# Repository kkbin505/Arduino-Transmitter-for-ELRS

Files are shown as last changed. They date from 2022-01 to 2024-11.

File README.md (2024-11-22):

# Simple TX

现已增加中文介绍，详情请看Wiki页面

This is an Arduino based RC transmitter TX. I want to design a RC transmitter (soft and hardware) that is simple to build, and use arduino board wich I am familler with, and it should supoort ELRS.

微信图片_20220213205906

video:

https://www.youtube.com/watch?v=BPLFkZUoV28

# Features:
- Support ExpressLRS 2.4G external TX module
- Up to 500Hz packet rate
- 4 analog channel
- 4 AUX channel

This project includes code, stl file for transmitter shell and pcb board, you can easily diy your own rc transmitter from arduino development board in a very simple way.

I have tested for 6 month since the first prototype (mod from an old Devo7), it works pretty well.

 * Simple TX is distributed in the hope that it will be useful, but WITHOUT ANY WARRANTY. 

I use superslim module in the shell, but any esp32 based tx module should be working.

It was tested for ELRS 1.0 and 2.0.

### Update:

### 2024/11/7 add 3 stage AUX channel
In branch 2.X maintance:
Because I have started flying fixed wing with iNav, current 7 channels are not enougth. So I added channel 8 and changed channel 6 (AUX2) from 2 postion switch to 3 postion. This is also for Betaflight. The 3 postion have to use 2 digital pins, currently I am using D3 and D8.

The current digital pin:

D2 - AUX3 

D3 - AUX2 low

D8 - AUX2 high

D4 - AUX1

D5 - AUX4

D6 - BUZZER

D7 - LED

### The development was moved to VS code 

### 2022/11/5 Move IDE to VSCODE and Arduino Extension

Add buzzer support on pin 6

The PIO becomes unusable dude to unstalbe network, so I switch back to arduino extension, still in VSCODE, because the original Arduino IDE is low efficient.

The code still works in Arduino IDE, you can compile in both enviroment

The PIO will be saved in a seprate branch and will unliked be updated

### 2022/6/3 Optimize Calibration

1. Add center stick calibration
2. Optimze channel reverse
	use 4 values to handdle reverse in config.h
	
// Define Reverse 1 = reverse, 0 = normal
	
Is_Aileron_Reverse  =1;
	
Is_Elevator_Reverse =1;
	
Is_Throttle_Reverse =0;
	
Is_Rudder_Reverse   =0;

### 2022/5/29 Calibration added

Calibration function added by erstec in Platformio_test_branch, thanks

1. enter debug mode by uncomment #define DEBUG
2. flash firmware to arduino nano
4. open serial monitor at 115200 baud, center stick and keep for 5 seconds
5. move stick full range within 20 seconds untill you see "Calibration Done"
6. comment //#define DEBUG and flash firmware to arduino nano
7. test in bf configurator
8. done

### 2022/4/6 Test branch

platformio

### Update Log 2022/4/3

Add Test branch for ppm output

### Update Log 2022/3/26

Update STL File：

Solve gimbal & switch interference

Add battery tray

ASSEMBLE

### Update Log 2022/3/20

Update PPM to ELRS library, siginal is more stable, still need more test

https://github.com/kkbin505/Arduino-Transmitter-for-ELRS/tree/main/PPMtoCRSF

### Update Log V0.9.3
Increase baud rate to 400K

*** In 400k baud, theoretical maxmum packet rate is 500Hz (400000/320bit per second, 1.6ms per frame). RC data pcket is 32byte=320bit(plus 1 start bit and 1 end bit).

Now simpleTX is supporting 500Hz

Add 3rd pre seeting for 500Hz 25mW

Gestrue:
Hold AILERON left and ELEVATOR up at power up.

### Update Log V0.9.2
Update cmd to elrs 2.0 (power setting commond of 2.0 is different from 1.0)

Re write gimbal calibation method, add center stick offset in config file

### Update Log V0.9.1
Add 2 pre settings for power and package rate:

Now you can enter setting 1 and 2 by gesutre:

Setting 1:
//250Hz 25mW

Hold AILERON left and ELEVATOR down at power up.

Setting 2:
//150Hz 100mW

Hold AILERON right and ELEVATOR up at power up.

Center stick will keep your previous setting.

Due to the hardware limitation of the ATMega328p, the follow functions are not supported:

* The 328p do not support inverted UART (which OpenTX use), there are 2 options:
	1. Tun  UART_INVERTED off.
	2. Adding a digital invert IC (I tested with SN74LS06N)

** Telemetray is off, 328p do not support half duplex.

The uart logic voltage of ESP32 is 3.3V, my ATMega328p is 5V. However mine TX work fine, it seems ESP32 UART is 5V tolerance.

#### Tips
Default RC channel order is AETR, you can change channel order whatever you like, by changing the RC channel order.
Current gimbal calibratin method is complex (but you need to do only once):
- Enter debug mode by delete "//" before #define DEBUG
- Flash with arduino IDE
- Open serialmonitor change baud rate to 115200
- Record max and min RC channel value and write in map() function (reverse order if neede)
   example:map(Aileron_value,893,223,RC_CHANNEL_MIN,RC_CHANNEL_MAX)
- Add "//" back before #define DEBUG
- Flash with arduino IDE

There are many amazing Expreslrs handset. But I want a simple arduino based transmitter for my DIY 2.4G external TX module.

https://youtu.be/PrfSfnqcBgk

### Add PCB V0.9

I replace the control board with my PCB and system.

微信图片_20220123195005

### 1. Project Intro:

### 1.1 Hardware (PCB)

In PCB folder, you can find the PCB and BOM, the PCB is designed in Easyeda and files in Gerber type. I orderd my PCB use the Gerber file from JLCpcb.

EasyEDA(标准版) - 免费、易用、强大的在线电路设计软件 - Google Chrome 2022_1_23 19_47_16

The PCB is v0.9 means it is not complete, but it works well at least for me. 

The version includes 4 digital switch, but I forget to wire out the LED pint, so I use one channel for LED only 3 digital available. 

The analogy channel support 3.3v gimbal (hall and poentional meter both works), the pin use 1.25 6p plug, it is the same pin order as most frsky gimbal (M7 for example). If you use orther gimbal pay attention to the pin order. I find jumper gimbal reversed GND(red) and 3.3V(black).

I powered my board with 2S battery, the arduino nano have a decent LDO （ASM1117）, and the ELRS module also powerd from 2S.

### 1.2 Firmware

All source codes are in SimpleTX folder.

It is writen in arduino frame use VScode, but arduino IDE should also work.

### 1.3 CAD-Model

3 versions of transmitter shell are available.

1 is a remix from https://github.com/cruwaller/elrs_handset



I removed 2 switch, and modify switch in front side from Switches to Tango2 like switch



Front_Shell_REV-A_M7_kkbin_modify.stl

2 is my design, it is compatibal with jumper TX 12 hall gimbal, very compact.



SimpleTX_Top_v15.stl

3 is for X9 lite gimbal, it feels too big for me.

!!! Do not solder the buzzer, need to add triode in next version, I burned my board.
buzzer

This Transmitter is inspired by cruwallero:
https://github.com/cruwaller/elrs_handset

Some code are based on  Pawel's amazing work on SBUS generate code.

https://quadmeup.com/generate-s-bus-with-arduino-in-a-simple-way/

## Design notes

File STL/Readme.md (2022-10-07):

Add STL file for print

微信图片_20220213205906

ASSEMBLE

Add a modify file from: https://github.com/cruwaller/elrs_handset/tree/master/revision_A/shell

Delete 2 top side switchs, modify front side switch to rectangle 19*7mm switch， give this design more tango2 kind of taste

Add gimbal protect for M7, print in TPU 20%

Add a open on the lower side for usb

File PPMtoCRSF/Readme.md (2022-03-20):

PPM to ELRS conveter

Use simpleTX PCB to make a ppm to ELRS converter

Plug PPM to D2 (switch 4 in pcb) and GND

This code is highly expermental, and unstable.

Make sure your transmitter output ppm correctly, otherwise the TX will receive noise singal, and transmit unexpected singal.

Use this arduino library:

https://github.com/DzikuVx/PPMReader

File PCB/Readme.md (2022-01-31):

Add PCB V0.9

BOM :
1. Frsky M7 Gimbal *2
2. Arduino Nano
3. XH2.45 3P *6
4. PH2.0 2P
5. 1.25 6P
6. 2 Position Switch *5
7. LED *1
8. 100 ohm resister 
9. 10K 0805 resister
10. 20K 0805 resister
11. UFL to SMA connector
12. 2.4G SMA antenna
13. ExpressLRS 2.4G TX module
14. 2S battery
15. PCB https://oshwlab.com/kkbinmail/arduino_transmitter

Build order:

1. Print shell from:https://github.com/cruwaller/elrs_handset/tree/master/revision_A/shell
2. Order PCB from JLB PCB
3. Sold 10K and 20K resiter to PCB
4. Sold 1.25 6P male header
5. Sold Arduino Nano
6. Sold XH2.45 (Double check the pole of the battery header, make sure ground is to ground)
7. Sold PH2.0
8. Down load firmware
9. Build and Flash to Arduino Nano with IDE
10. Flash TX module use ExpressLRS un-check UART_INVERTOR & OpenTX_SYNC
11. Assemble switch to shell
12. Assemble M7 Gimbal
13. Assemble SMA connector
14. Connect everything

SCHEAM

EasyEDA(标准版) - 免费、易用、强大的在线电路设计软件 - Google Chrome 2022_1_23 19_47_16

微信图片_20220123194957

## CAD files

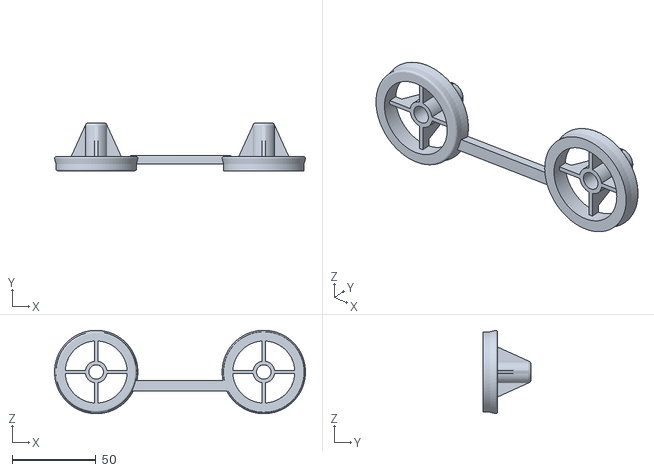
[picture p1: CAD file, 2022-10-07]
STL/Front_Shell_REV-A_M7_kkbin_modify_gimbal Cover v2.stl
149.8 x 28.4 x 49.8

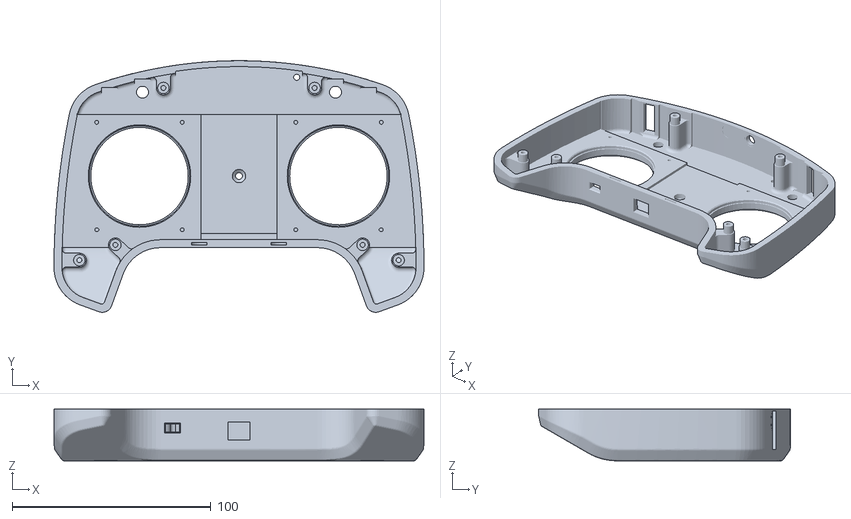
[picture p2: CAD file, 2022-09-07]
STL/Front_Shell_REV-A_M7_kkbin_modify.stl
186.0 x 126.5 x 26.0

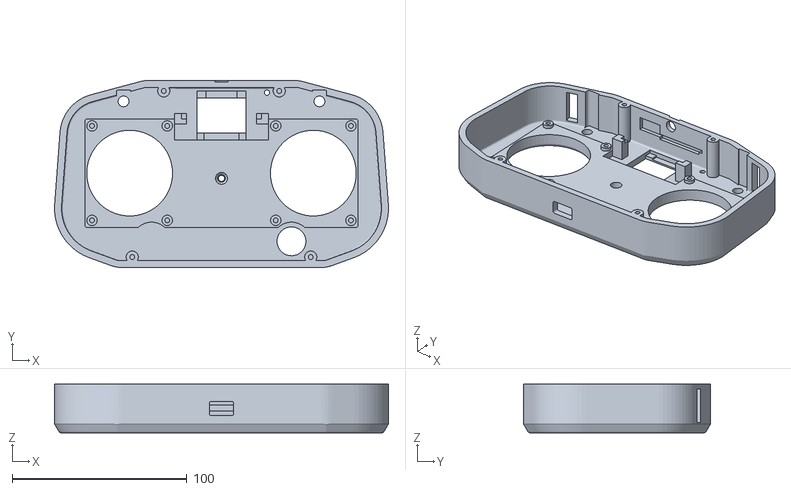
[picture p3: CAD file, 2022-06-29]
STL/SimpleTX_Top_Frsky_X9Lite_S.stl
190.9 x 107.0 x 28.0

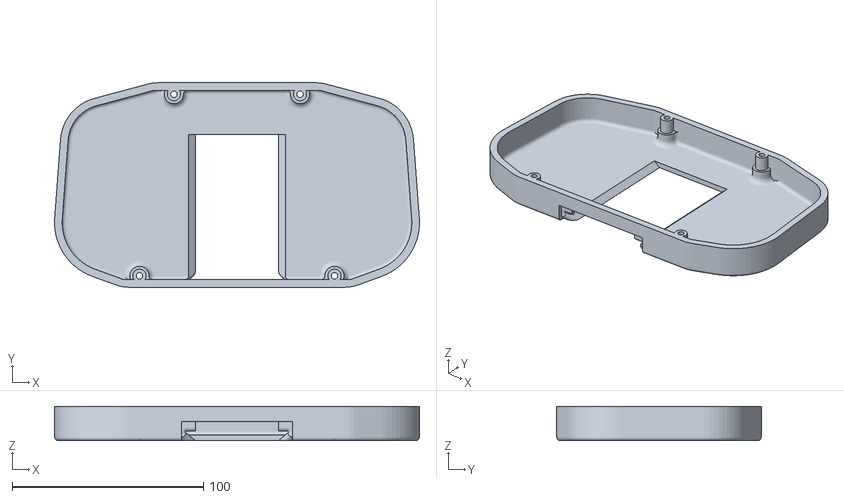
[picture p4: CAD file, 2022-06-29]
STL/SimpleTX_Buttom Frsky_X9Lite_S.stl
190.9 x 107.0 x 18.0

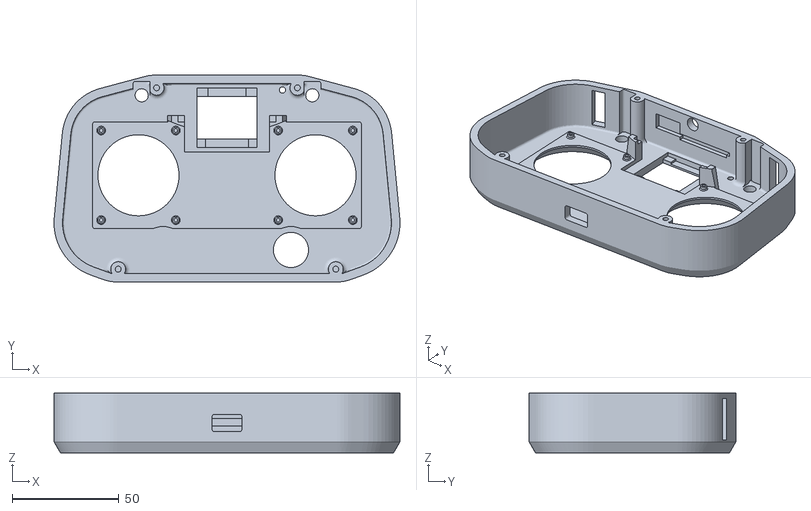
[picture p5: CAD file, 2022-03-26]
STL/SimpleTX_Top_v15.stl
162.2 x 97.0 x 28.0

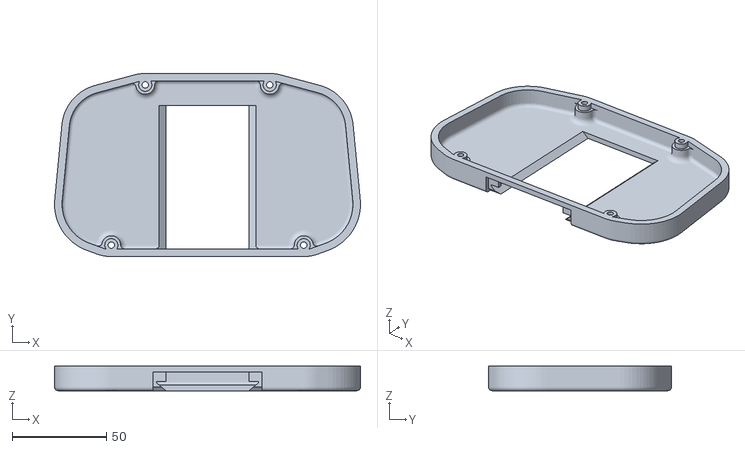
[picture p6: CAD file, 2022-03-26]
STL/SimpleTX_Buttom v15.stl
162.2 x 97.0 x 13.0

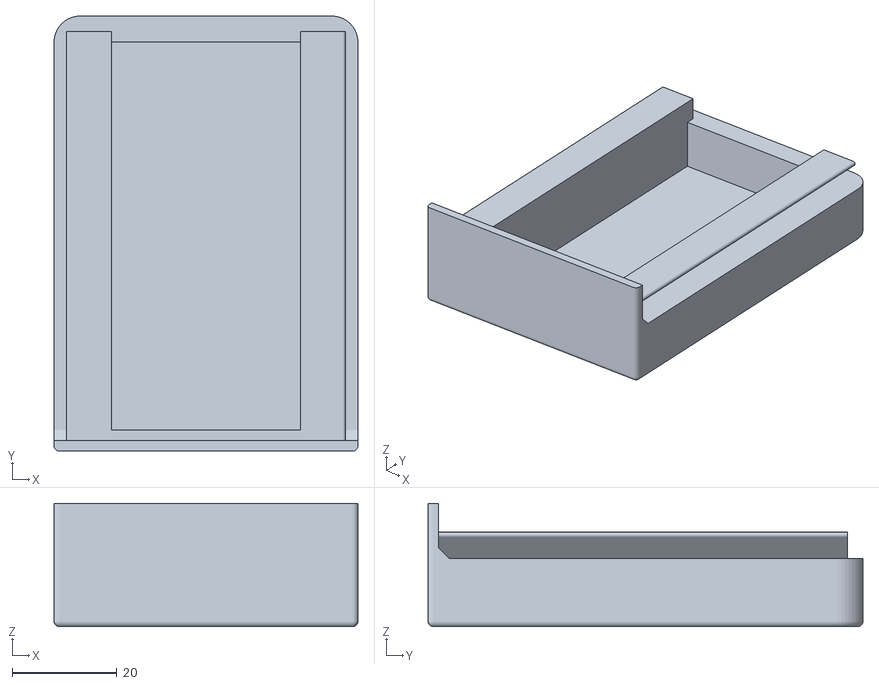
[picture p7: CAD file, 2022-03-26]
STL/SimpleTX_Battery_Bay v15.stl
58.0 x 83.0 x 23.5

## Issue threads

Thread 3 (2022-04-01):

Why not just use ELRS+stick for Transmitter

hjchjcjh, 2022-04-01:
It is recommended to integrate all applications into the ELRS, because esp32 has many ADCs and the joystick can be directly connected to the ADC of ESP32,

kkbin505, 2022-04-05:
That a good suggestion.
The transmitter as it's name is to keep code simple. If integrate all staff in the esp32, the code will be too complex.
Second, simpletx decouple the fast development of the expresslrs repo, the main code of simpletx will be compatabile from expresslrs 1.0 all the way to 2.3 and further. It is easier to maintain.
If you are looking for directly ADC to expresslrs, you can alway find information in the expresslrs handset repo:
https://github.com/ExpressLRS/ExpressLRS-Hardware

Closed 2022-04-05.

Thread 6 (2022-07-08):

About RC Channel

mrAyaz, 2022-07-08:
thanks for this wonderful project. Can you tell me how many channels this project supports. I need 10 channels is this possible?

kkbin505, 2022-07-12:
Thanks for your support.
The Arduino nano I used have (A0 to A7) 8 analogy IO and (D2 to D13) 12 digital IO, so it can have 20 channels in theory, but crsf current only transfer 16 channels.
So my answer for this question for this question is yes, it can support 10 channels, you can add more channels use free Its and add code your self.

kkbin505, 2022-07-12:
Thanks for your support.
The Arduino nano I used have (A0 to A7) 8 analogy IO and (D2 to D13) 12 digital IO, so it can have 20 channels in theory, but crsf current only transfer 16 channels.
So my answer for this question for this question is yes, it can support 10 channels, you can add more channels use free Its and add code your self.

mrAyaz, 2022-07-12:
Can you show? You have a example?

kkbin505, 2022-07-16:
You can add more channels by adding more io in the config:
const int DIGITAL_PIN_SWITCH_AUX4 = 5;(pin 5 is a free io pin)

add this line in main to avoid float
pinMode(DIGITAL_PIN_SWITCH_AUX4, INPUT_PULLUP);

Add :
AUX4_value = digitalRead(DIGITAL_PIN_SWITCH_AUX4);
and:
rcChannels[AUX4] = (AUX4_value == 0) ? CRSF_DIGITAL_CHANNEL_MIN : CRSF_DIGITAL_CHANNEL_MAX;

you can add upto 12 aux channels

kkbin505, 2022-08-20:
The limilation is only the IO pins, close the issue

kkbin505, 2022-08-20:
The limilation is only the IO pins, close the issue

Closed 2022-08-20.

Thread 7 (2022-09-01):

PPM Output?

TheBellmanHimself, 2022-09-01:
Unfortunately I have been put in the position where I need to use PPM output from the arduino to a module.  But something doesn't seem to be working.

With PPMOUTPUT defined the flight controller seems to get a partially valid PPM stream with the arduino directly connected, it receives the default positions.  All the aux switch channels seem to work.  But no stick movement is happening.

Something I missed?  I'm testing on an Uno instead of a nano at the moment, is there some quirk to the interrupt pins between the two?

Thanks

kkbin505, 2022-11-02:
This is not an issue

Closed 2022-11-03.

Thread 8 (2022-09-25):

About ExpressLRS 3.0

mrAyaz, 2022-09-25:
Hi dear Developer. please tell me SimpleTX support Express LRS 3.0 or not. And now i make a RC baset on SimpleTX but my TX module (Happymodel 2.4 GHz) blink only Blue LED. why? please help. i connect only joystic Gimbal 4 chanel.

kkbin505, 2022-09-27:
SimpleTX support ELRS 3.0 in the way that gimbal data can be transfer to the TX moduel, because the communication between TX and the transmitter dosen't change since ELRS 1.0 (CRSF protocol). But the simpleTX do not support power or fresh rate config for 3.0 yet (plan to do that).
For the Happymodel moduel,  do you follow every step in my readme file, I can not test because I use DIY module (JR, nano and super slim) all of them works fine, most importand thing is uncheck - uart invert, because simpleTX only support un inverted uart on avr micro controller I use.

tmb-ix, 2023-06-15:
Hello.
on version 3.2, the modules establish a connection. But the channels are not transmitted. Tell me, is there a solution?

galaxyrepairman, 2023-11-23:
Hello, according to your video operation, it seems that there is no need to burn the PPM to CRFS protocol into Arduino. Is it actually necessary to burn it into Arduino?

galaxyrepairman, 2023-11-23:
我使用elrs2.5.1版本无法对频

sercona, 2024-08-02:
> Hello. on version 3.2, the modules establish a connection. But the channels are not transmitted. Tell me, is there a solution?

is it possible that you are using the wrong pad on the elrs 'rx as tx' chip?

this happened to me.  I wired the tx uart pad on the nano cpu to the tx pad on the elrs module and that was incorrect.  I tried using the rx pad on the elrs module and finally I was able to see data come thru.  so that's one thing to check.  only 1 wire for data is used on the elrs module.  its clear that the tx (data-out) is the right one for nano since the nano is in 'transmit only' mode.  but it was not clear to me which line on the elrs module was the one to use.  try one, then try the other.  that allowed me to see data come thru.

kkbin505, 2024-11-22:
Elrs 3.0 and 2.0 use the same rc data protocal called crsf ground protocal. So currently it should work on elrs 3.0 in theory. It is only the guesture configuration will not work on elrs 3.0. I am working on update it .

kkbinmail, 2025-02-12:
ELRS 3.0 support added in the main branch

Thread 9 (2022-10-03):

有个疑问 ，电路图上 arduino TX是直连高频头，高频头用ESP32 输入电平是3.3V； Arduino 输出电平是5V的 这样不会有问题吗？

geekli, 2022-10-03:

trogalko, 2022-10-04:
For ESP32, VCC must 3.3V, but IO is 5V tolerant. Please check here : https://www.qworqs.com/2021/05/19/are-the-esp32-and-esp8266-5v-tolerant-yes-they-officially-are/

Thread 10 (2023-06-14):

Custom RC with switches only

not7cd, 2023-06-14:
Hey, I was building a custom case with only switches and used your code as a library. I have some issues sending the actual commands and setting a proper Packet Rate.

Here are the specs of our project:
* Arduino MEGA, the source code shares process time with ethernet connection and MQTT messages.
* We are using Nano module, I had no luck with JR micro module
* ExpressLRS 3.2.1. Which version did you use?
* I have set different Packet Rate

What is happening:
* Handset detected by Nano TX Module
* Connects to RX module
* No inputs visible on the flight controller side

Maybe you have some ways to debug this, as
Our source code: https://gitlab.com/SimLE/simba/control-panel-software

I would be grateful if you could help soon.

MattiasKallio, 2023-06-14:
Hi!

I'm not sure why I got this message, I am not involved in that project at
all.

But it's weirdly close to things I do, so I had to go through some code to
be sure. 😂

Cheers
//Mattias

Den ons 14 juni 2023 22:07Norbert Szulc ***@***.***> skrev:

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

kkbin505, 2024-11-12:
Did you make it?

ne9n, 2024-11-12:
no not yet.  It is on deck for a winter project.
I have several never used old RC transmitters I would like to convert to a
new encoder and RF deck.  I wanted to use 50 Mhz as I am a ham but saw ELRS
and am looking at it.

I am an EE manager and my day job is very close to this so, it will be a
fun project.

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

Closed 2024-11-22.

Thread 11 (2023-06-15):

SimpleTX support ELRS 3.0 in the way that gimbal data can be transfer to the TX moduel, because the communication between TX and the transmitter dosen't change since ELRS 1.0 (CRSF protocol). But the simpleTX do not support power or fresh rate config for 3.0 yet (plan to do that).

tmb-ix, 2023-06-15:
SimpleTX support ELRS 3.0 in the way that gimbal data can be transfer to the TX moduel, because the communication between TX and the transmitter dosen't change since ELRS 1.0 (CRSF protocol). But the simpleTX do not support power or fresh rate config for 3.0 yet (plan to do that).
For the Happymodel moduel,  do you follow every step in my readme file, I can not test because I use DIY module (JR, nano and super slim) all of them works fine, most importand thing is uncheck - uart invert, because simpleTX only support un inverted uart on avr micro controller I use.

_Originally posted by @kkbin505 in https://github.com/kkbin505/Arduino-Transmitter-for-ELRS/issues/8#issuecomment-1259518158_

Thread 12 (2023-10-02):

Adding channels

ArshaanTech, 2023-10-02:
This supports upto 12 channels ryt? I was wondering how to add up to 8 analog inputs as channels... other than 4 for joysticks.

longlong7211, 2023-12-02:
I think you can add it yourself in the code. It's not too difficult to find the code to add a few channels. The author's PCB has no space left so I think he doesn't support adding channels, but that code is ready for adding some channels

ArshaanTech, 2023-12-09:
Oh okay thanks.

Closed 2023-12-09.

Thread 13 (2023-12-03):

Support for Un-Inverted CRSF

inx199, 2023-12-03:
Iam using custom build firmware on my R9M, and i cant change the UART_INVERTED option, I know arduino can't output Un-inverted CRSF, but can it be done via hardware that can simply inverse the signal? or by using ESP32 which support signal inversion?

sercona, 2024-08-02:
yes, the simplest solution is to use a logic gate and literally invert the uart signal.  note you may need 3.3v logic (likely so).

kkbin505, 2024-08-30:
> Iam using custom build firmware on my R9M, and i cant change the UART_INVERTED option, I know arduino can't output Un-inverted CRSF, but can it be done via hardware that can simply inverse the signal? or by using ESP32 which support signal inversion?

For arduino based simple TX, you need a logical invert gate to do that.
If you need to implement uart-inverted in the TX side, my suggestion is to use ESP32 based simple TX instead which have build inverted uart option.
https://github.com/danxdz/simpleTx_esp32

Closed 2024-08-30.

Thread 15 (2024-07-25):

Analog inputs not working

ArshaanTech, 2024-07-25:
Here's the analog input pins in the config file:

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

And this is the output (not changing when sticks are moved):

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

sercona, 2024-08-02:
you must calibrate, first.  I think that was something I did wrong, also.

calibration tells the system the min and max of the sweep.  if it defaults to all the same midpoint, no sticks will be seen as 'moving'.

I think that's the issue.

ArshaanTech, 2024-08-03:
I tried to caliberate it aswell,
I uploaded the code after with caliberation, but it doesn't seem to work :(

ArshaanTech, 2024-08-03:
even during caliberation, it shows no changes.

sercona, 2024-08-03:
did you connect the a-ref pin on the arduino nano to 3.3v (right next to it)?

are you sure your gimbals are not wired backwards?  I have radiomaster boxer gimbals and red is MINUS and black is PLUS.  dammit.  stupid radiomaster.  if your hall gimbals (which care about polarity) are not wired right you wont get any analog variation out.

simplest test, just run a short test program that reads from a single analog in and prints its output.  just that.  if you cant get a single analog in with the joystick you need to figure out if its voltage or what the issue is.

you could start with a cheap pot (1k or 10k) and try connecting its wiper to the analog input pin and when you connect ground to one end and 3.3v to the other, you should see values change.

ArshaanTech, 2024-08-03:
No i did not connect the a-rf pin on arduino nano to 3.3v, Is it important?
My gimbals are working fine with a different code for a transmitter.
I will try connecting a-ref to 3.3v.

sercona, 2024-08-03:
the code wants to use an external voltage ref.  so yeah, you HAVE to since it assumes a 3.3v ref; the same supply that you use for the gimbal positive rail.

sercona, 2024-08-03:
if your code has:

  **analogReference(EXTERNAL);**

then yes, you need those 2 pins shorted (3.3v and a-ref)

ArshaanTech, 2024-08-04:
Thank you so much, I just got it working!

Closed 2024-08-04.

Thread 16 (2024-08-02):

digital buttons doesnt work

womihako, 2024-08-02:
Hi, this is a nice project and i did it.
So i have connection to the Flight controllor and also can see the analog inputs.
but the switches doesnt work. maybe can get some help?

sercona, 2024-08-18:
are you sure you have the right gpio numbers?  and you are using switches to connect those to ground?

I have 4 switches working; 2 2-pos and 2 3-pos and they all work ok.  you have to check the code to make sure that all your switches have code that runs (not commented out, etc).

kkbin505, 2024-12-13:
This is not a software issue, it may be related to some wiring issue. Please check your diagram.

Closed 2024-12-13.

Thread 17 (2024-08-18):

Not able to bind.

ArshaanTech, 2024-08-18:
Hi,
I am not able to bind my receiver with my my DIY Tx module and simple TX. How do i put my Tx into bind mode??

sercona, 2024-08-18:
elrs v2 and v3 seem to have changed and I dont think the stick based binding works anymore.  what I've done is to go into the web ui for the rx-as-tx module and define what the boot button does.  if you dont have a button, you should have a pad and ground to short.  wire up a button to that and mount it on the tx chassis.

triple power cycle the rx and it should be waiting in bind mode.  press the bind button on your tx briefly and the bind process should complete.

note, 250hz is the default for the rx-as-tx and so your rx will have to 'settle' on 250hz to get quicker bind.  what often is helpful is to use your main tx (edgetx) and set its elrs to 250hz and get your quad to bind.  once it binds at 250, go into elrs lua menu on the tx and change it from 250 down to something and then back to 250.  all while the quad is still on and had a bind lock from the edgetx tx.  this will cause short failsafes and once you are bound back to 250, you can power off your edgetx radio and then power on the diy one.  the bind should happen faster now (the quad remembers the 250 and your tx only will talk at 250 unless the host protocol is updated to v3)

ArshaanTech, 2024-08-18:
Can you tell me how can i go to the webui rx as tx and define the bind button, I am really new and i don't know how to do that...
I don't have any ratdio with edgeTX. I am currently making this SimpleTX...
Thank you.

sercona, 2024-08-18:
it will be more helpful to have a 'master' edgetx radio just to make sure your rx is working ok.  if you have only your diy tx, when things dont work, how do you know which end is the problem?

the rx should go into wifi mode after 30 or 60 seconds.  it will blink fast.  go to your phone(etc) and look for the expresslrs wifi AP.  connect to that, then either go into its web ui (10.0.0.1) or give it your own wifi ssid/pass and it will reboot into your network.  either way, the web ui will have a tab that talks about the button that is part of all elrs rx's.  even if just a solder pad marked 'boot'.

ArshaanTech, 2024-08-18:
> it will be more helpful to have a 'master' edgetx radio just to make sure your rx is working ok. if you have only your diy tx, when things dont work, how do you know which end is the problem?
>
> the rx should go into wifi mode after 30 or 60 seconds. it will blink fast. go to your phone(etc) and look for the expresslrs wifi AP. connect to that, then either go into its web ui (10.0.0.1) or give it your own wifi ssid/pass and it will reboot into your network. either way, the web ui will have a tab that talks about the button that is part of all elrs rx's. even if just a solder pad marked 'boot'.

Okay i did that... What should i do next how do i bind my Tx to that Rx?

sercona, 2024-08-19:
for the basic question, you might want to ask on the elrs discord.  read the faq for elrs and you should get all you need.

kkbin505, 2024-08-30:
> Hi, I am not able to bind my receiver with my my DIY Tx module and simple TX. How do i put my Tx into bind mode??

Simple TX does not support TX bind and have no plan to support in the future. How I bind the TX to the RX is ulitize the ELRS binding phase. All my receives are set the same bind pahse as the TX, they will automantically bind when powered up.

kkbin505, 2024-08-30:
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

The ELRS repo or discord is a better place to discusse this topic. There are more people can help you there.

Closed 2024-08-30.

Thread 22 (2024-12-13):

How can i start Ble Joystick using gesture tried using "ELRS_BLE_JOYSTIC_COMMAND" but it only starts wifi mode .

Okami-423, 2024-12-13:

Okami-423, 2024-12-15:
For anyone wanting to use SimpleTX as Joystick i am writing this solution that i found which is to solder a Push button to one of the GPIO pin of ESP32 and write the pin on button pin on Hardware.html and then set button to start BLE_JOYSTICK_MODE on webui.

Closed 2024-12-15.

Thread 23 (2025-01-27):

Port SimpleTX From Arduino Nano to ESP32 or STM32 for more features and to support Full-Duplex for Telemetry for ELRS Using generic OLED Display.

Okami-423, 2025-01-27:
Hi, kkbin505
i have seen your simpleTX video and Also Build my own simpleTX and i love it for how simple it is to use but i can not ignore how underpowered it is compared to the boards available in same price bracket in 2025, So i would like to see you build a version of simpleTX for ESP32 or STM32 with telemetry but i do not possess such coding skills to build it on own, So i would love it if you could build it.
Thank You

basha318i, 2025-02-10:
I'm trying to port this to also be used with RC cars, where merely throttle & steering are used, it would be nice to get a cheap RC car controller & convert it to ELRS! Thanks.

kkbin505, 2025-02-12:
I am not planing to add complex feaures to simpleTX.
BTW other people have already implement the telementry etc.
Please check a ESP32 based SimpleTX
https://github.com/danxdz/simpleTx_esp32
and STM32 based simpleTX
https://github.com/danxdz/simpleTx_esp32

Okami-423, 2025-02-12:
Oh really i did not know about it.
Thanks for sharing other links
Really appreciate IT.

Closed 2025-02-12.

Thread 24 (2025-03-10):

Stm32

Lalbabu2001, 2025-03-10:
Why not you use stm32 instead of Arduino, it's fast, higher stick resolution etc.

kkbin505, 2025-03-12:
First, thanks for your attention on this project. The reason I keep arduino is I want to keep this project as simple as possible, the feature is enougth for me so far. Of course the stm32 is more powerful, so there is already a branch based on stm32, checkout this repo: https://github.com/kkbin505/STM32-ELRS-Handset

Closed 2025-03-12.

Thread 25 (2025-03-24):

Setting output power

kallaspriit, 2025-03-24:
Hey,

Your codebase includes setting the output power of the ExpressLRS transmitter but have You tested it that it actually works for you?

I'm using a Radiomaster Ranger Micro TX and I can send the channels just fine but changing the output power does not have any effect.

It's hard to find exactly what the packet should be for setting the power. What did You base your code off of?

kkbin505, 2025-03-29:
Thanks for point out this issue, it seems the power change logic of 3.0 changed from 2.0, I am trying to workout.

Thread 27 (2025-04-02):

CH7

55johnchiu, 2025-04-02:
希望多一個三位掣 CH7上

kkbin505, 2025-04-05:
如果要实现三段，还需要一个pin，你希望是哪个pin

55johnchiu, 2025-04-07:
9,pin可以嗎?

55johnchiu, 2025-04-07:
我在2.x新增,正常運作

// pins that used for the switch
const int DIGITAL_PIN_SWITCH_ARM = 2;  // default arm switch for Elrs is channel 5 (digital 1)
const int DIGITAL_PIN_SWITCH_AUX2_HIGH = 7; // 3 stage switch for mode setup
const int DIGITAL_PIN_SWITCH_AUX2_LOW = 8; //
const int DIGITAL_PIN_SWITCH_AUX3_HIGH = 4; //const int DIGITAL_PIN_SWITCH_AUX3 = 4;
const int DIGITAL_PIN_SWITCH_AUX3_LOW = 9;//
const int DIGITAL_PIN_SWITCH_AUX4 = 3;  //

// pins that used for output
const int DIGITAL_PIN_LED = 5;    // in pcb v0.9 led is reused from AUX4 (remember to add 300om resistor between led and 5 digital output)
// pins that used for buzzer
const int DIGITAL_PIN_BUZZER = 6;
//----- Voltage monitoring -------------------------
// Define battery warning voltage
const float WARNING_VOLTAGE = 7.4; // 2S Lipo 3.7v per cell
const float BEEPING_VOLTAGE = 7.0; // 2S Lipo 3.5v per cell
const float ON_USB = 5.2;          // On USB power / no battery

kkbin505, 2025-04-07:
好的，这个功能我就不放到正式版本里了。

Closed 2025-04-07.

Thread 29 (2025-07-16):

Connecting a readymade module to the nano

Infilux, 2025-07-16:
Hi, I am connecting a readily available Expresslrs module to the DIY radio but it not working. I am using radiomaster nomad module. I have connected everything on the breadboad, only change is, instead of the LoRa module I am using the radiomasted nomad but its not working the way it should. Kindly let us know where is the issue.

Product link: https://radiomasterrc.com/collections/nomad/products/nomad-dual-1-watt-gemini-xrossband-expresslrs-module

kkbin505, 2025-07-17:
Which elrs version did your tx use

Infilux, 2025-07-17:
lastest 3.5.6

Infilux, 2025-07-17:
See, I will be honest, I havent bought all the recommended hardware yet. I have got a nano on my breadbord, where I am trying to sent 1 single input from my nomad module to the RX connecte to FC(Monitering on betaflight). I just want to see that when I press a button it is reflected on the betaflight channel monitor. Once this is confirm I will place order for all the required stuff and build the complete TX. I have tried but no input are transmitted yet. The module is bound to the RX and the TX pin is connected to the s-port pin of the module and a switch is connected. Kindly guide me.

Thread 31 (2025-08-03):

Flashing to Arduino Uno R4 not possible

R4pidFire, 2025-08-03:
Hi, is it possible to flash this to an Arduino Uno? I am get a compilation error because of the interrupt service function (I guess because it's a different MCU) and also there is a deprecated function.

```
/home/rapid/Dev/Arduino/Arduino-Transmitter-for-ELRS-main/SimpleTX/SimpleTX.ino:671:5: error: expected constructor, destructor, or type conversion before '(' token
 ISR(TIMER1_COMPA_vect) { // leave this alone
     ^
/home/rapid/Dev/Arduino/Arduino-Transmitter-for-ELRS-main/SimpleTX/SimpleTX.ino: In function 'void setup()':
/home/rapid/Dev/Arduino/Arduino-Transmitter-for-ELRS-main/SimpleTX/SimpleTX.ino:393:21: error: 'EXTERNAL' was not declared in this scope
     analogReference(EXTERNAL);
                     ^~~~~~~~
/home/rapid/Dev/Arduino/Arduino-Transmitter-for-ELRS-main/SimpleTX/SimpleTX.ino:393:21: note: suggested alternative: 'AR_EXTERNAL'
     analogReference(EXTERNAL);
                     ^~~~~~~~
                     AR_EXTERNAL
/home/rapid/Dev/Arduino/Arduino-Transmitter-for-ELRS-main/SimpleTX/SimpleTX.ino: At global scope:
/home/rapid/Dev/Arduino/Arduino-Transmitter-for-ELRS-main/SimpleTX/SimpleTX.ino:671:4: error: expected constructor, destructor, or type conversion before '(' token
 ISR(TIMER1_COMPA_vect) { // leave this alone
    ^
exit status 1

Compilation error: expected constructor, destructor, or type conversion before '(' token
```

kkbin505, 2025-08-05:
Arduino Uno is OK, but In my understanding Uno R4 is different MCU.  If the logical R4 is 3.3v instead of 5v, since most modern MCU use 3.ev , you do not need to use analogReference(EXTERNAL). Just directly hook up poteniometer to the ADC of MCU.

Closed 2025-08-05.

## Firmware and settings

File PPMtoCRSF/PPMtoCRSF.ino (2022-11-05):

/* 
-------------------------------------------------------------------------
 Simple Arduino trasmisster (PPM to ELRS)
 Decode PPM to CRSF protocol
 Arduino Nano
 ELRS 2.4G TX moduel
 Custom PCB from JLCPCB
 https://github.com/kkbin505/Arduino-Transmitter-for-ELRS
 * This file is part of Simple TX
 *
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
 * You should have received a copy of the GNU General Public License
 * along with Cleanflight.  If not, see <http://www.gnu.org/licenses/>.
 */

//Use this lib https://github.com/DzikuVx/PPMReader
#include "PPMReader.h"
//Setup ppm read on pin 2, 

PPMReader ppmReader(2, 0, false);

byte channelAmount = 8;

//default channel order is  AETR
#define TAER

#define RADIO_ADDRESS                  0xEA
#define ADDR_MODULE                    0xEE  //  Crossfire transmitter
#define TYPE_CHANNELS                  0x16

// internal crsf variables
#define CRSF_CHANNEL_MIN 172
#define CRSF_CHANNEL_MID 991
#define CRSF_CHANNEL_MAX 1811
#define CRSF_TIME_NEEDED_PER_FRAME_US   1100 // 700 ms + 400 ms for potential ad-hoc request
#define CRSF_TIME_BETWEEN_FRAMES_US     4000 // 4 ms 250Hz
#define CRSF_PAYLOAD_OFFSET offsetof(crsfFrameDef_t, type)
#define CRSF_MAX_CHANNEL 16
#define CRSF_FRAME_SIZE_MAX 64
#define SERIAL_BAUDRATE 400000
#define CRSF_MSP_RX_BUF_SIZE 128
#define CRSF_MSP_TX_BUF_SIZE 128
#define CRSF_PAYLOAD_SIZE_MAX   60
#define CRSF_PACKET_LENGTH 22
#define CRSF_PACKET_SIZE  26
#define CRSF_FRAME_LENGTH 24;   // length of type + payload + crc

uint8_t crsfPacket[CRSF_PACKET_SIZE];
int rcChannels[CRSF_MAX_CHANNEL];
uint32_t crsfTime = 0;

#ifdef TAER
enum chan_order{
    THROTTLE, 
    AILERON,
    ELEVATOR,
    RUDDER,
    AUX1,  // (CH5)  ARM switch for Expresslrs
    AUX2,  // (CH6)  angel / airmode change
    AUX3,  // (CH7)  flip after crash
    AUX4,  // (CH8) 
    AUX5,  // (CH9) 
    AUX6,  // (CH10) 
    AUX7,  // (CH11)
    AUX8,  // (CH12)
};
#else
enum chan_order{
    AILERON,
    ELEVATOR,
    THROTTLE, 
    RUDDER,
    AUX1,  // (CH5)  ARM switch for Expresslrs
    AUX2,  // (CH6)  angel / airmode change
    AUX3,  // (CH7)  flip after crash
    AUX4,  // (CH8) 
    AUX5,  // (CH9) 
    AUX6,  // (CH10) 
    AUX7,  // (CH11)
    AUX8,  // (CH12)
};
#endif

void setup()
{
  /*
  TCCR1A = 0;  //reset timer1
  TCCR1B = 0;
  TCCR1B |= (1 << CS11);  //set timer1 to increment every 0,5 us or 1us on 8MHz
  */
  for (uint8_t i = 0; i < CRSF_MAX_CHANNEL; i++) {
        rcChannels[i] = CRSF_CHANNEL_MID;
    }
    rcChannels[THROTTLE] = CRSF_CHANNEL_MIN; // Throttle
 
    delay(1000);
    Serial.begin(SERIAL_BAUDRATE);
  
    //Serial.begin(115200);
    //Serial.println("ready");
}

void loop()
{
  uint32_t currentMicros = micros();

 if(ppmReader.isReceiving()==true){
  int count;
  while(ppmReader.get(count) != 0){  //print out the servo values
     int value = ppmReader.get(count);;
     rcChannels[count]=map(value,1000,2000,CRSF_CHANNEL_MIN,CRSF_CHANNEL_MAX);
    //Serial.print(ppmReader.get(count));
    //Serial.print("  ");
    count++;
  }
 }
  //set fail safe value
else{
    rcChannels[THROTTLE] = CRSF_CHANNEL_MIN; // 
    rcChannels[AILERON] = CRSF_CHANNEL_MID; // 
    rcChannels[ELEVATOR] = CRSF_CHANNEL_MID; // 
    rcChannels[RUDDER] = CRSF_CHANNEL_MID; // 
    rcChannels[AUX1] = CRSF_CHANNEL_MIN; // ARM Low
  }
  
    if (currentMicros > crsfTime) {
        crsfPreparePacket(crsfPacket, rcChannels);
        Serial.write(crsfPacket, CRSF_PACKET_SIZE);            
        crsfTime = currentMicros + CRSF_TIME_BETWEEN_FRAMES_US;
    }

}

// crc implementation from CRSF protocol document rev7
static u8 crsf_crc8tab[256] = {
    0x00, 0xD5, 0x7F, 0xAA, 0xFE, 0x2B, 0x81, 0x54, 0x29, 0xFC, 0x56, 0x83, 0xD7, 0x02, 0xA8, 0x7D,
    0x52, 0x87, 0x2D, 0xF8, 0xAC, 0x79, 0xD3, 0x06, 0x7B, 0xAE, 0x04, 0xD1, 0x85, 0x50, 0xFA, 0x2F,
    0xA4, 0x71, 0xDB, 0x0E, 0x5A, 0x8F, 0x25, 0xF0, 0x8D, 0x58, 0xF2, 0x27, 0x73, 0xA6, 0x0C, 0xD9,
    0xF6, 0x23, 0x89, 0x5C, 0x08, 0xDD, 0x77, 0xA2, 0xDF, 0x0A, 0xA0, 0x75, 0x21, 0xF4, 0x5E, 0x8B,
    0x9D, 0x48, 0xE2, 0x37, 0x63, 0xB6, 0x1C, 0xC9, 0xB4, 0x61, 0xCB, 0x1E, 0x4A, 0x9F, 0x35, 0xE0,
    0xCF, 0x1A, 0xB0, 0x65, 0x31, 0xE4, 0x4E, 0x9B, 0xE6, 0x33, 0x99, 0x4C, 0x18, 0xCD, 0x67, 0xB2,
    0x39, 0xEC, 0x46, 0x93, 0xC7, 0x12, 0xB8, 0x6D, 0x10, 0xC5, 0x6F, 0xBA, 0xEE, 0x3B, 0x91, 0x44,
    0x6B, 0xBE, 0x14, 0xC1, 0x95, 0x40, 0xEA, 0x3F, 0x42, 0x97, 0x3D, 0xE8, 0xBC, 0x69, 0xC3, 0x16,
    0xEF, 0x3A, 0x90, 0x45, 0x11, 0xC4, 0x6E, 0xBB, 0xC6, 0x13, 0xB9, 0x6C, 0x38, 0xED, 0x47, 0x92,
    0xBD, 0x68, 0xC2, 0x17, 0x43, 0x96, 0x3C, 0xE9, 0x94, 0x41, 0xEB, 0x3E, 0x6A, 0xBF, 0x15, 0xC0,
    0x4B, 0x9E, 0x34, 0xE1, 0xB5, 0x60, 0xCA, 0x1F, 0x62, 0xB7, 0x1D, 0xC8, 0x9C, 0x49, 0xE3, 0x36,
    0x19, 0xCC, 0x66, 0xB3, 0xE7, 0x32, 0x98, 0x4D, 0x30, 0xE5, 0x4F, 0x9A, 0xCE, 0x1B, 0xB1, 0x64,
    0x72, 0xA7, 0x0D, 0xD8, 0x8C, 0x59, 0xF3, 0x26, 0x5B, 0x8E, 0x24, 0xF1, 0xA5, 0x70, 0xDA, 0x0F,
    0x20, 0xF5, 0x5F, 0x8A, 0xDE, 0x0B, 0xA1, 0x74, 0x09, 0xDC, 0x76, 0xA3, 0xF7, 0x22, 0x88, 0x5D,
    0xD6, 0x03, 0xA9, 0x7C, 0x28, 0xFD, 0x57, 0x82, 0xFF, 0x2A, 0x80, 0x55, 0x01, 0xD4, 0x7E, 0xAB,
    0x84, 0x51, 0xFB, 0x2E, 0x7A, 0xAF, 0x05, 0xD0, 0xAD, 0x78, 0xD2, 0x07, 0x53, 0x86, 0x2C, 0xF9};

u8 crsf_crc8(const u8 *ptr, u8 len) {
    u8 crc = 0;
    for (u8 i=0; i < len; i++) {
        crc = crsf_crc8tab[crc ^ *ptr++];
    }
    return crc;
}

void crsfPreparePacket(uint8_t packet[], int channels[]){

    static int output[CRSF_MAX_CHANNEL] = {0};
    const uint8_t crc = crsf_crc8(&packet[2], CRSF_PACKET_SIZE-3);
    /*
     * Map 1000-2000 with middle at 1500 chanel values to
     * 173-1811 with middle at 992 S.BUS protocol requires
     */
    for (uint8_t i = 0; i < CRSF_MAX_CHANNEL; i++) {
        output[i] = channels[i];
    }    
   /*    
       Serial.print("crsf  "); 
       Serial.print(output[0]); 
       Serial.print("  i"); 
       Serial.print(output[1]); 
       Serial.print("  i"); 
       Serial.print(output[2]); 
       Serial.print("  i"); 
       Serial.print(output[3]); 
       Serial.println(); */

    // packet[0] = UART_SYNC; //Header
    packet[0] = ADDR_MODULE; //Header
    packet[1] = 24;   // length of type (24) + payload + crc
    packet[2] = TYPE_CHANNELS;
    packet[3] = (uint8_t) (channels[0] & 0x07FF);
    packet[4] = (uint8_t) ((channels[0] & 0x07FF)>>8 | (channels[1] & 0x07FF)<<3);
    packet[5] = (uint8_t) ((channels[1] & 0x07FF)>>5 | (channels[2] & 0x07FF)<<6);
    packet[6] = (uint8_t) ((channels[2] & 0x07FF)>>2);
    packet[7] = (uint8_t) ((channels[2] & 0x07FF)>>10 | (channels[3] & 0x07FF)<<1);
    packet[8] = (uint8_t) ((channels[3] & 0x07FF)>>7 | (channels[4] & 0x07FF)<<4);
    packet[9] = (uint8_t) ((channels[4] & 0x07FF)>>4 | (channels[5] & 0x07FF)<<7);
    packet[10] = (uint8_t) ((channels[5] & 0x07FF)>>1);
    packet[11] = (uint8_t) ((channels[5] & 0x07FF)>>9 | (channels[6] & 0x07FF)<<2);
    packet[12] = (uint8_t) ((channels[6] & 0x07FF)>>6 | (channels[7] & 0x07FF)<<5);
    packet[13] = (uint8_t) ((channels[7] & 0x07FF)>>3);
    packet[14] = (uint8_t) ((channels[8] & 0x07FF));
    packet[15] = (uint8_t) ((channels[8] & 0x07FF)>>8 | (channels[9] & 0x07FF)<<3);
    packet[16] = (uint8_t) ((channels[9] & 0x07FF)>>5 | (channels[10] & 0x07FF)<<6);  
    packet[17] = (uint8_t) ((channels[10] & 0x07FF)>>2);
    packet[18] = (uint8_t) ((channels[10] & 0x07FF)>>10 | (channels[11] & 0x07FF)<<1);
    packet[19] = (uint8_t) ((channels[11] & 0x07FF)>>7 | (channels[12] & 0x07FF)<<4);
    packet[20] = (uint8_t) ((channels[12] & 0x07FF)>>4  | (channels[13] & 0x07FF)<<7);
    packet[21] = (uint8_t) ((channels[13] & 0x07FF)>>1);
    packet[22] = (uint8_t) ((channels[13] & 0x07FF)>>9  | (channels[14] & 0x07FF)<<2);
    packet[23] = (uint8_t) ((channels[14] & 0x07FF)>>6  | (channels[15] & 0x07FF)<<5);
    packet[24] = (uint8_t) ((channels[15] & 0x07FF)>>3);
    
    packet[25] = crsf_crc8(&packet[2], CRSF_PACKET_SIZE-3); //CRC


}

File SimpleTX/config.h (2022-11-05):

/*
 * This file is part of Simple TX
 *
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
 * You should have received a copy of the GNU General Public License
 * along with Cleanflight.  If not, see <http://www.gnu.org/licenses/>.
 */

//#define USE_M7

/*
 =======================================================================================================
 Simple TX CONFIG OPTIONS (comment out unneeded options)
 =======================================================================================================
 */
// Define analogy input limite

#define ADC_MIN 0
#define ADC_MID 511
#define ADC_MAX 1023


#define ANALOG_CUTOFF 150 // cut off lower and upper end to avoid un-symmetric joystick range in trade off resolution

// Define RC input Offset
#ifdef USE_M7
// M7
int Aileron_OFFSET    = -46;
int Elevator_OFFSET   = 57;
int Throttle_OFFSET   = 0;
int Rudder_OFFSET     = -18;
#else
// stat war
int Aileron_OFFSET    = 0;
int Elevator_OFFSET   = 0;
int Throttle_OFFSET   = 0;
int Rudder_OFFSET     = 0;
#endif

// Define Reverse 1=reverse
int Is_Aileron_Reverse  =1;
int Is_Elevator_Reverse =0;
int Is_Throttle_Reverse =0;
int Is_Rudder_Reverse   =0;

// IO setup
// pins that used for the Joystick
const int analogInPinAileron = A4;
const int analogInPinElevator = A3;
const int analogInPinThrottle = A2;
const int analogInPinRudder = A1;
const int VOLTAGE_READ_PIN = A0;

// pins that used for the switch
const int DIGITAL_PIN_SWITCH_ARM = 4;  // Arm switch
const int DIGITAL_PIN_SWITCH_AUX2 = 3; //
const int DIGITAL_PIN_SWITCH_AUX3 = 2;  //
// const int DIGITAL_PIN_SWITCH_AUX4 = 5;  //

// pins that used for output
const int DIGITAL_PIN_LED = 5;    // in pcb v0.9 led is reused from AUX4 (remember to add 300om resistor in led)
//const int DIGITAL_PIN_BUZZER = 7; // do not use in pcb v0.9

// pins that used for buzzer
const int DIGITAL_PIN_BUZZER = 6;
//----- Voltage monitoring -------------------------
// Define battery warning voltage
const float WARNING_VOLTAGE = 7.4; // 2S Lipo 3.7v per cell
const float BEEPING_VOLTAGE = 7.0; // 2S Lipo 3.5v per cell

// Define Commond for start Up Setting
#define RC_MIN_COMMAND 600
#define RC_MAX_COMMAND 1400

// Define stick unmove alarm time
#define STICK_ALARM_TIME 30000

// from https://github.com/DeviationTX/deviation/pull/1009/ ELRS menu implement in deviation TX
/*static uint8_t  currentPktRate =1; //  "250Hz", "150Hz", "50Hz"
  //                                       1        3       5
static uint8_t  currentPower =1 ;//  "10mW", "25mW", "50mW", "100mW", "250mW"
  //                                   0     1         2        3        4
*/
// ELRS 2.0:
//  1 : Set Lua [Packet Rate]= 0 - 50Hz / 1 - 150Hz / 3 - 250Hz
//  2 : Set Lua [Telem Ratio]= 0 - off / 1 - 1:128 / 2 - 1:64 / 3 - 1:32 / 4 - 1:16 / 5 - 1:8 / 6 - 1:4 / 7 - 1:2
//  3 : Set Lua [Switch Mode]=0 -> Hybrid;Wide
//  4 : Set Lua [Model Match]=0 -> Off;On
//  5 : Set Lua [TX Power]=0 - 10mW / 1 - 25mW / 2 - 50mW /3 - 100mW/4 - 250mW
// 3 Default Settings
#define SETTING_1_PktRate 2 // 250Hz
#define SETTING_1_Power 1   // 25mW

#define SETTING_2_PktRate 1 // 150Hz
#define SETTING_2_Power 3   // 100mW

#define SETTING_3_PktRate 3 // 500Hz
#define SETTING_3_Power 1   // 25mW

enum chan_order
{
    AILERON,
    ELEVATOR,
    THROTTLE,
    RUDDER,
    AUX1, // (CH5)  ARM switch for Expresslrs
    AUX2, // (CH6)  angel / airmode change
    AUX3, // (CH7)  flip after crash
    AUX4, // (CH8)
    AUX5, // (CH9)
    AUX6, // (CH10)
    AUX7, // (CH11)
    AUX8, // (CH12)
};

//#define PPMOUTPUT
//-------------------- PPM Config-------------------------
#define CHANNEL_NUMBER 12          // set the number of chanels
#define CHANNEL_DEFAULT_VALUE 1500 // set the default servo value
#define FRAME_LENGTH 22500         // set the PPM frame length in microseconds (1ms = 1000µs)
#define PULSE_LENGTH 300           // set the pulse length
#define onState 1                  // set polarity of the pulses: 1 is positive, 0 is negative
#define ppmPin 2                   // set PPM signal output pin on the arduino

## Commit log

2022-01-04 Change TX module power and packet rate implemented
    Based on the deviation pull for T8SG elrs setup menu.
    This change implement the setup package, you have to manually setup the code. And press button to update the setup in the TX module.
    Optimization needed to remove the press operation.
    https://github.com/DeviationTX/deviation/pull/1009/
2022-01-17 Re orgnize file structure
    Move function out independent of main file.
    Battery for voltage management.
    crsf.c for crsf packet function.
    LED blink function.
2022-01-23 Add 3D print link
2022-01-23 Create PCB.md
    Add PCB file.
2022-01-25 Add PCB Gerber File V0.9
2022-01-31 Add pcb link
    https://oshwlab.com/kkbinmail/arduino_transmitter
2022-02-04 Bug fix
    The fix the bug, gesture only change packet rate but not power.
2022-02-10 Correct default setting 1 and 2 number.
    [config.h]
2022-02-11 Add ANALOG_CUTOFF
    cut off lower and upper end to avoid un-symmetric joystick range in trade off resolution
    [config.h]
2022-02-13 Add my shell design
    [SimpleTX_Bottom.stl, SimpleTX_TOP.stl, SimpleTX_Top_OLED.stl]
2022-02-13 Add STL file
2022-03-04 Increase baud rate to 400K
    Increase serial baud rate to 400k, capable of running 500Hz pakcet rate.
2022-03-09 Add 500Hz setting
2022-03-09 Add third seeting (500Hz)
2022-03-09 400K baud for 500Hz packet rate update
2022-03-26 Update shell, add battery tray.
    [SimpleTX v15.stl, SimpleTX_Battery_Bay v15.stl, SimpleTX_Buttom v15.stl]
2022-06-29 stl update
    Add support for frsky X9 lite S hall gimbal G7H92
    [SimpleTX_Buttom Frsky_X9Lite_S.stl, SimpleTX_Top_Frsky_X9Lite_S.stl, SimpleTX_Top_v15.stl]
2022-09-07 Modify cruwaller desigen
    This is a modify shell from:https://github.com/cruwaller/elrs_handset/tree/master/revision_A/shell
    [Front_Shell_REV-A_M7_kkbin_modify.stl]
2022-10-07 Add gimbal protect for M7
    Add gimbal protect for M7, print in TPU 20%
    [Front_Shell_REV-A_M7_kkbin_modify_gimbal Cover v2.stl]
2022-11-05 Switch IDE back to VSCODE
    Use VSCODE and arduino IDE extension instead of PIO
2022-12-09 Update README.md
    Add CAD picture

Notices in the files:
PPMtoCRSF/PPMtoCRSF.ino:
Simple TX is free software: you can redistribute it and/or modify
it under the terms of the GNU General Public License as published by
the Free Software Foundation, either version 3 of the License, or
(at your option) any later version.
